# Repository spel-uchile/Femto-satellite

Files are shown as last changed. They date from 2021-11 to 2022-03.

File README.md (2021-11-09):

# README #

Femto-satellite v3.211109

### Description ###

This is a low-cost satellite of less than 100 grams. The goal is to deploy two femto-satellites from a 3U CubeSat to validate a localization system based on TDOA and AOA.

### Current features ###

 * GPS localization
 * S band communication
 * 32-bit ARM Cortex M0+ microcontroller
 * Magnetometer PNI RM3100
 * Data logger using a microSD card
 
### To do ###

 * Update the software for the new hardware version
 * Program a low-power mode

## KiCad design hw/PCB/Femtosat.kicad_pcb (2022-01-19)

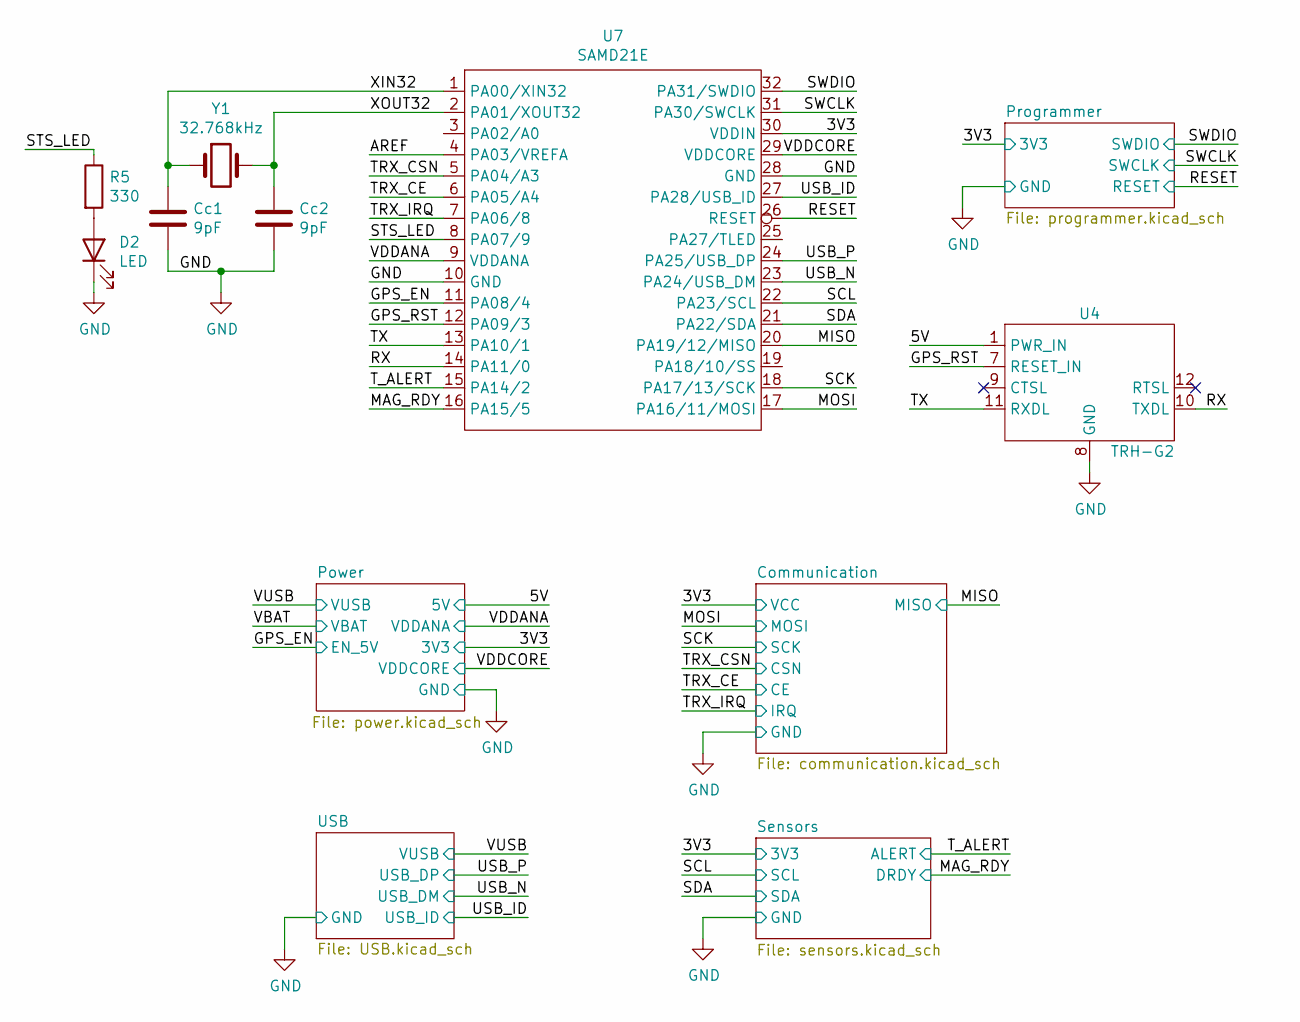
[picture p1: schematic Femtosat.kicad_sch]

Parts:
Cc1, Cc2: 9pF; C_0603_1608Metric_Pad1.05x0.95mm_HandSolder
D2: LED; LED_0805_2012Metric_Pad1.15x1.40mm_HandSolder
R5: 330; R_0603_1608Metric_Pad1.05x0.95mm_HandSolder
U4: TRH-G2; TRH-G2_extended
U7: SAMD21E; TQFP-32_7x7mm_P0.8mm
Y1: 32.768kHz; Crystal_SMD_EuroQuartz_EQ161-2Pin_3.2x1.5mm_HandSoldering

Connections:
+3V3: U7.30 (VDDIN); also elsewhere on the board
/5V: U4.1 (PWR_IN), U4.2 (PWR_IN); also elsewhere on the board
/AREF: U7.4 (PA03/VREFA)
/GPS_EN: U7.11 (PA08/4); also elsewhere on the board
/GPS_RST: U4.7 (RESET_IN), U7.12 (PA09/3)
/MAG_RDY: U7.16 (PA15/5); also elsewhere on the board
/MISO: U7.20 (PA19/12/MISO); also elsewhere on the board
/MOSI: U7.17 (PA16/11/MOSI); also elsewhere on the board
/RESET: U7.26 (RESET); also elsewhere on the board
/RX: U4.10 (TXDL), U7.14 (PA11/0)
/SCK: U7.18 (PA17/13/SCK); also elsewhere on the board
/SCL: U7.22 (PA23/SCL); also elsewhere on the board
/SDA: U7.21 (PA22/SDA); also elsewhere on the board
/STS_LED: R5.1, U7.8 (PA07/9)
/SWCLK: U7.31 (PA30/SWCLK); also elsewhere on the board
/SWDIO: U7.32 (PA31/SWDIO); also elsewhere on the board
/TRX_CE: U7.6 (PA05/A4); also elsewhere on the board
/TRX_CSN: U7.5 (PA04/A3); also elsewhere on the board
/TRX_IRQ: U7.7 (PA06/8); also elsewhere on the board
/TX: U4.11 (RXDL), U7.13 (PA10/1)
/T_ALERT: U7.15 (PA14/2); also elsewhere on the board
/USB_ID: U7.27 (PA28/USB_ID); also elsewhere on the board
/USB_N: U7.23 (PA24/USB_DM); also elsewhere on the board
/USB_P: U7.24 (PA25/USB_DP); also elsewhere on the board
/VDDANA: U7.9 (VDDANA); also elsewhere on the board
/VDDCORE: U7.29 (VDDCORE); also elsewhere on the board
/XIN32: Cc1.1, U7.1 (PA00/XIN32), Y1.1
/XOUT32: Cc2.1, U7.2 (PA01/XOUT32), Y1.2
GND: Cc1.2, Cc2.2, D2.1 (K), U4.3 (PGND), U4.4 (PGND), U4.5 (-), U4.6 (-), U4.8 (GND), U7.10 (GND), U7.28 (GND); also elsewhere on the board
unnamed: D2.2 (A), R5.2

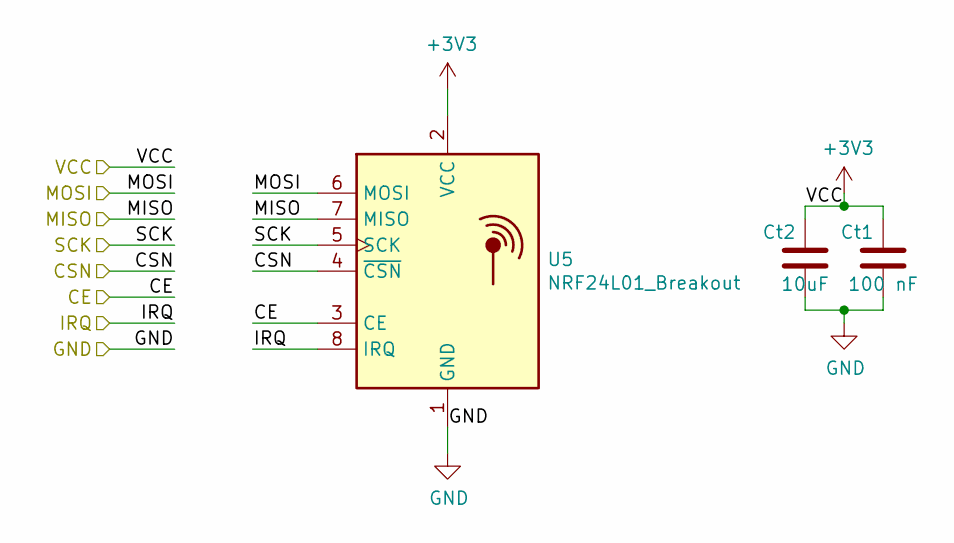
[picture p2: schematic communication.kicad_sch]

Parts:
Ct1: 100 nF; C_0603_1608Metric_Pad1.05x0.95mm_HandSolder
Ct2: 10uF; C_0603_1608Metric_Pad1.05x0.95mm_HandSolder
U5: NRF24L01_Breakout; nRF24L01_long

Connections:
+3V3: Ct1.2, Ct2.2, U5.2 (VCC); also elsewhere on the board
/MISO: U5.7 (MISO); also elsewhere on the board
/MOSI: U5.6 (MOSI); also elsewhere on the board
/SCK: U5.5 (SCK); also elsewhere on the board
/TRX_CE: U5.3 (CE); also elsewhere on the board
/TRX_CSN: U5.4 (~CSN); also elsewhere on the board
/TRX_IRQ: U5.8 (IRQ); also elsewhere on the board
GND: Ct1.1, Ct2.1, U5.1 (GND); also elsewhere on the board

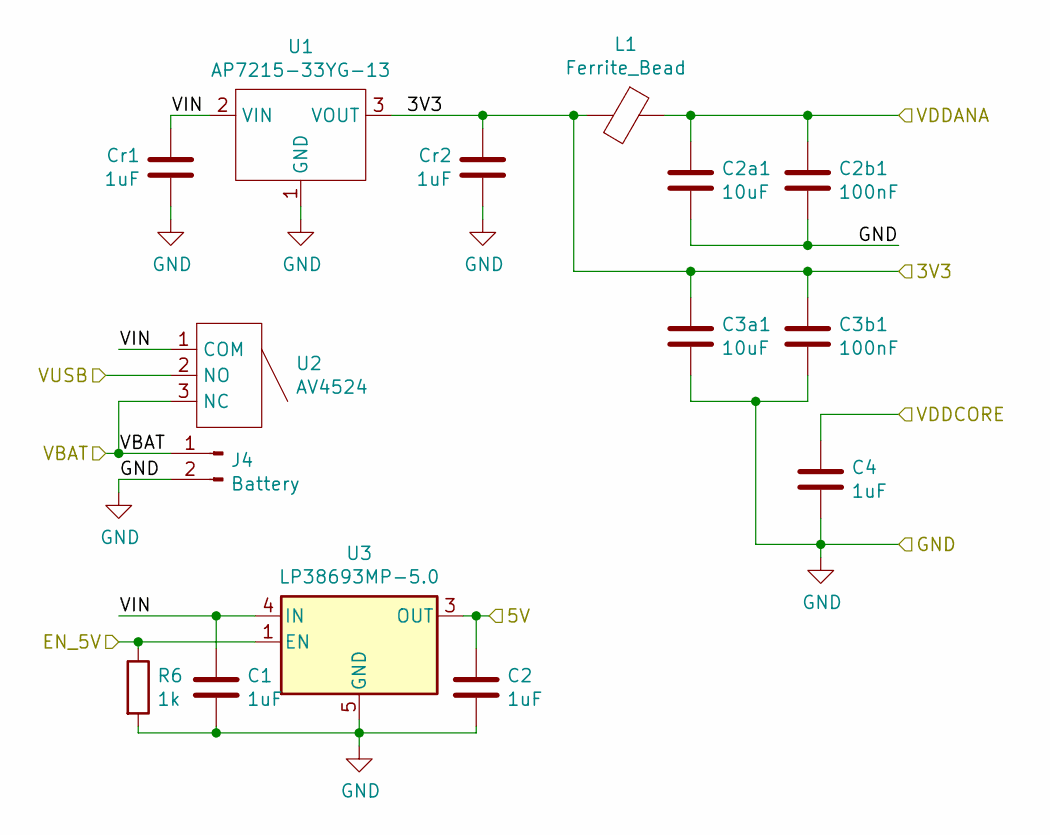
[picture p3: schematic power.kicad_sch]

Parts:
C1, C2, C4: 1uF; C_0603_1608Metric_Pad1.05x0.95mm_HandSolder
C2a1, C3a1: 10uF; C_0603_1608Metric_Pad1.05x0.95mm_HandSolder
C2b1, C3b1: 100nF; C_0603_1608Metric_Pad1.05x0.95mm_HandSolder
Cr1, Cr2: 1uF; C_0603_1608Metric_Pad1.05x0.95mm_HandSolder
J4: Battery; JST_PH_S2B-PH-K_1x02_P2.00mm_Horizontal
L1: Ferrite_Bead; L_0805_2012Metric_Pad1.15x1.40mm_HandSolder
R6: 1k; R_0603_1608Metric_Pad1.05x0.95mm_HandSolder
U1: AP7215-33YG-13; SOT-89-3
U2: AV4524
U3: LP38693MP-5.0; SOT-223-5

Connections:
+3V3: C3a1.1, C3b1.1, Cr2.1, L1.2, U1.3 (VOUT); also elsewhere on the board
/5V: C2.1, U3.3 (OUT); also elsewhere on the board
/GPS_EN: R6.1, U3.1 (EN); also elsewhere on the board
/Power/VIN: C1.1, Cr1.1, U1.2 (VIN), U2.1 (COM), U3.4 (IN)
/VBAT: J4.1, U2.3 (NC)
/VDDANA: C2a1.1, C2b1.1, L1.1; also elsewhere on the board
/VDDCORE: C4.1; also elsewhere on the board
/VUSB: U2.2 (NO); also elsewhere on the board
GND: C1.2, C2.2, C2a1.2, C2b1.2, C3a1.2, C3b1.2, C4.2, Cr1.2, Cr2.2, J4.2, R6.2, U1.1 (GND), U3.5 (GND); also elsewhere on the board

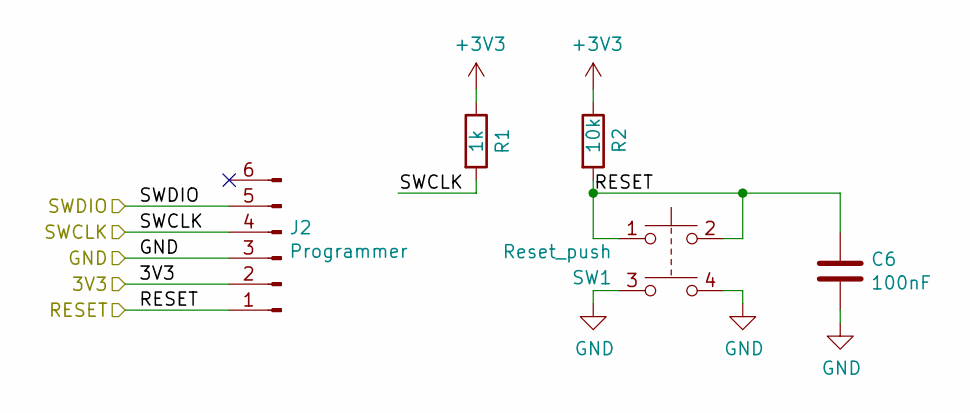
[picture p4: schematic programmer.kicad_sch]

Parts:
C6: 100nF; C_0603_1608Metric_Pad1.05x0.95mm_HandSolder
J2: Programmer; Molex_PicoBlade_53261-0671_1x06-1MP_P1.25mm_Horizontal
R1: 1k; R_0603_1608Metric_Pad1.05x0.95mm_HandSolder
R2: 10k; R_0603_1608Metric_Pad1.05x0.95mm_HandSolder
SW1: Reset_push; SW_TH_Tactile_Omron_B3F-10xx

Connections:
+3V3: J2.2, R1.1, R2.1; also elsewhere on the board
/RESET: C6.1, J2.1, R2.2, SW1.1, SW1.2; also elsewhere on the board
/SWCLK: J2.4, R1.2; also elsewhere on the board
/SWDIO: J2.5; also elsewhere on the board
GND: C6.2, J2.3, SW1.3, SW1.4; also elsewhere on the board

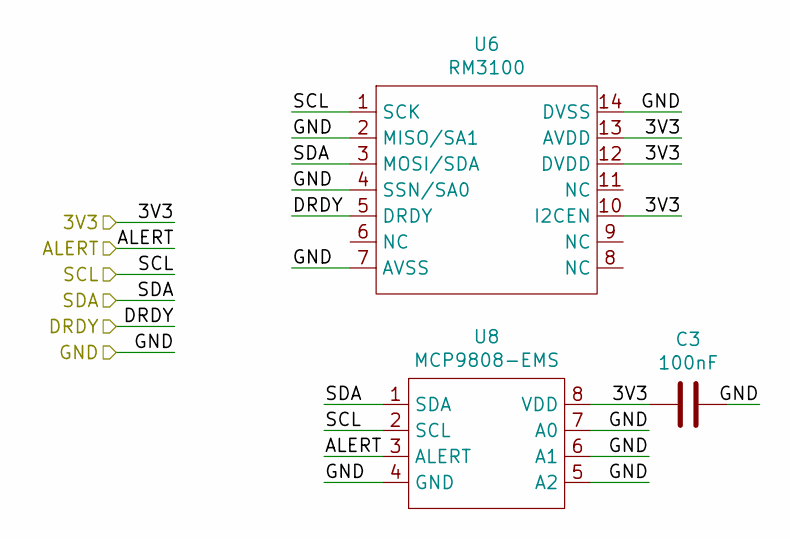
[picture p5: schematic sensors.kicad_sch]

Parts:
C3: 100nF; C_0603_1608Metric_Pad1.05x0.95mm_HandSolder
U6: RM3100
U8: MCP9808-EMS; MSOP-8_3x3mm_P0.65mm

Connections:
+3V3: C3.1, U6.10 (I2CEN), U6.12 (DVDD), U6.13 (AVDD), U8.8 (VDD); also elsewhere on the board
/MAG_RDY: U6.5 (DRDY); also elsewhere on the board
/SCL: U6.1 (SCK), U8.2 (SCL); also elsewhere on the board
/SDA: U6.3 (MOSI/SDA), U8.1 (SDA); also elsewhere on the board
/T_ALERT: U8.3 (ALERT); also elsewhere on the board
GND: C3.2, U6.2 (MISO/SA1), U6.4 (SSN/SA0), U6.7 (AVSS), U6.14 (DVSS), U8.4 (GND), U8.5 (A2), U8.6 (A1), U8.7 (A0); also elsewhere on the board

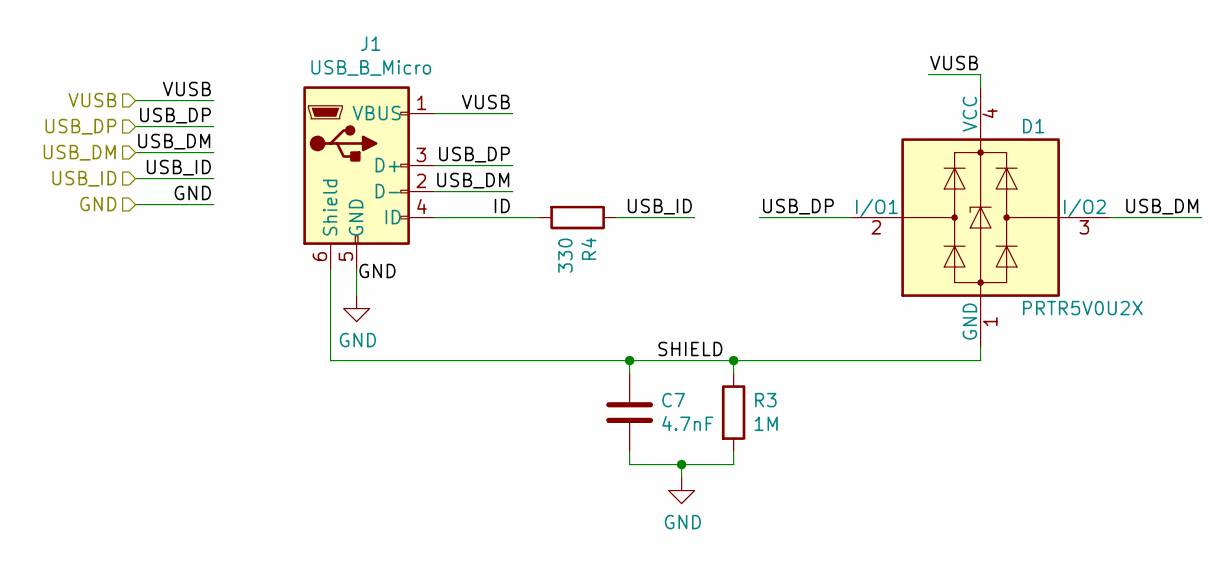
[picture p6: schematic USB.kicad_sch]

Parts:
C7: 4.7nF; C_0603_1608Metric_Pad1.05x0.95mm_HandSolder
D1: PRTR5V0U2X; SOT-143
J1: USB_B_Micro; USB_Micro-B_Molex_47346-0001
R3: 1M; R_0603_1608Metric_Pad1.05x0.95mm_HandSolder
R4: 330; R_0603_1608Metric_Pad1.05x0.95mm_HandSolder

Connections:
/USB/ID: J1.4 (ID), R4.2
/USB/SHIELD: C7.1, D1.1 (GND), J1.6 (Shield), R3.1
/USB_ID: R4.1; also elsewhere on the board
/USB_N: D1.3 (I/O2), J1.2 (D-); also elsewhere on the board
/USB_P: D1.2 (I/O1), J1.3 (D+); also elsewhere on the board
/VUSB: D1.4 (VCC), J1.1 (VBUS); also elsewhere on the board
GND: C7.2, J1.5 (GND), R3.2; also elsewhere on the board

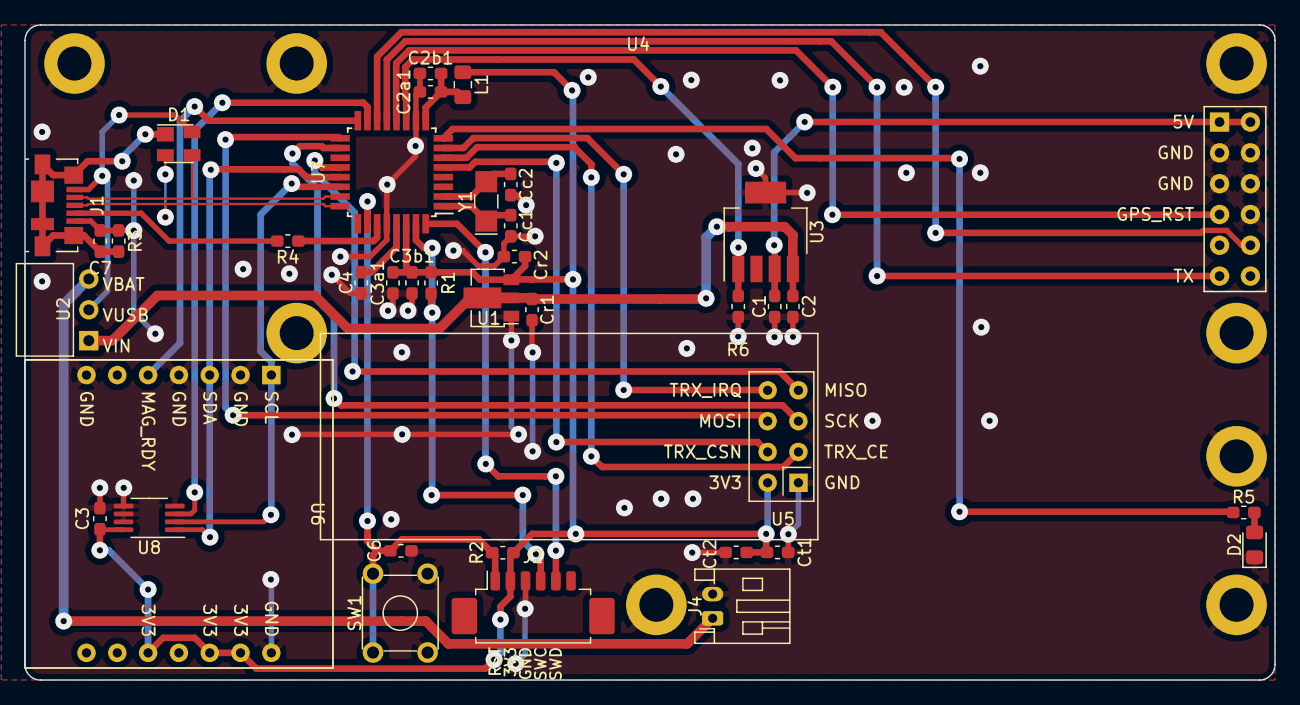
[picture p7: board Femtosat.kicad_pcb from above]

Board: 2 copper layers, 103.1 x 54.0 mm, 38 parts (0 on the bottom side), 34 nets.

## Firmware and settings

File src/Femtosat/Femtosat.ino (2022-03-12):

#include <RTCZero.h>
#include <SPI.h>
#include <Wire.h>
#include "RF24.h"
#include "PNI_RM3100.h"
#include "gps.h"
#include "temp.h"

#define serial SerialUSB
#define STATUS_LED 9
#define RADIO_CE_PIN A4
#define RADIO_CSN_PIN A3
#define MAG_RDY 5
#define TRX_IRQ 8
#define TEMP_ALERT 2
#define START_TRANSMISSION 1

SPIClass mySPI (&sercom1, 12, 13, 11, SPI_PAD_0_SCK_1, SERCOM_RX_PAD_3);
// Instantiate an object for the nRF24L01 transceiver
RF24 radio(RADIO_CE_PIN, RADIO_CSN_PIN, 1000000);
// Instantiate an object for the RM3100 Magnetometer
PNI_RM3100 mag;
// Instantiate an object for the JAVAD GNSS receiver
GPS javad(115200);
// Instantiate an object for the MCP9808 temperature sensor
TEMP temp(0x18);
// Create an rtc object 
RTCZero rtc;

uint8_t address[4][8] = {"Femto 1", "Femto 2", "SUCHAI2", "SUCHAI3"};
uint8_t radioNumber = 1;

// Used to control whether this node is sending or receiving
bool role = false;  // true = TX role, false = RX role

bool mag_debug = false;
bool temp_debug = false;
bool gps_debug = false;
bool trx_debug = false;
uint32_t cmd = 0;
const uint32_t max_samples = 400;
uint32_t transmit_index = 0;

typedef struct{
    uint32_t node = 0;
    uint32_t index = 0;
    uint32_t date = 241121;
    uint32_t time = 16132231;
    int32_t latitude = -3345782;
    int32_t longitude = -7066167;
    int32_t altitude = 505500;
    uint32_t num_sats = 15;
} gnss_data_t;
gnss_data_t gnss_data[max_samples];

typedef struct{
    uint32_t node = 0;
    uint32_t index = 0;
    int32_t fe_mag_x = 5782;
    int32_t fe_mag_y = 6167;
    int32_t fe_mag_z = 9055;
    float temp = 25.0;
} mag_data_t;
mag_data_t mag_data[max_samples];

uint32_t sizeof_gnss_data = sizeof(gnss_data_t);
uint32_t sizeof_mag_data = sizeof(mag_data_t);

void setup() {
    delay(1000);
    Wire.begin();
    pinMode(RADIO_CSN_PIN, OUTPUT);
    digitalWrite(RADIO_CSN_PIN, LOW);
    pinMode(STATUS_LED, OUTPUT);
    digitalWrite(STATUS_LED, LOW);
    pinMode(MAG_RDY, INPUT);
    serial.begin(115200);
    javad.init();
    temp.init();
    if (!mag.begin()) {
        serial.println(F("Could not find a valid RM3100 sensor, check wiring or "
                     "try a different address!"));
    }
    serial.println(F("RM_3100 connected"));
    serial.println(F("Initializing the magnetometer..."));
    /* Default settings from datasheet. */
    int ccx = 3200; /**< Count Cycles for x sensor measurement. It must be between 30 an 400 (default 200) */
    int ccy = 3200; /**< Count Cycles for y sensor measurement. It must be between 30 an 400 (default 200) */
    int ccz = 3200; /**< Count Cycles for z sensor measurement. It must be between 30 an 400 (default 200) */
    mag.setSampling(PNI_RM3100::MODE_CMMXYZ,     /* Operating Mode. MODE_SINGLE MODE_CMMXYZ MODE_CMMX MODE_CMMY MODE_CMMZ*/
                    PNI_RM3100::TMRC_HZ,         /* Max frequency */
                    ccx,    /**< Count Cycles for x sensor measurement. It must be between 30 an 400 (default 200) */
                    ccy,    /**< Count Cycles for y sensor measurement. It must be between 30 an 400 (default 200) */
                    ccz,    /**< Count Cycles for z sensor measurement. It must be between 30 an 400 (default 200) */
                    1);
    serial.println(F("Done."));
    while (!radio.begin(&mySPI, RADIO_CE_PIN, RADIO_CSN_PIN)) {
        serial.println(F("Radio hardware is not responding!!"));
        delay(1000);
    }
    serial.println(F("Initializing radio hardware..."));
    radio.setPALevel(RF24_PA_MAX);//LOW);  // RF24_PA_MAX is default.
    radio.setPayloadSize(sizeof_gnss_data);
    radio.openWritingPipe(address[radioNumber]);
    radio.openReadingPipe(1, address[3]);
    radio.setDataRate(RF24_250KBPS);
    radio.setChannel(55); // 2400 + 55 = 2455 MHz
    radio.startListening(); // put radio in RX mode
    serial.println(F("Done."));
    serial.println(F("Initializing RTC..."));
    rtc.begin();
    rtc.setTime((byte) 0, (byte) 0, (byte) 0);
    rtc.setDate((byte) 0, (byte) 0, (byte) 0);
    serial.println(F("Done."));
    digitalWrite(STATUS_LED, HIGH);
    delay(5000);
    digitalWrite(STATUS_LED, LOW);
    //role = true;
    //cmd = 8;
    serial.println(F("Starting initial measurement."));
    updateData();
    serial.println(F("Done."));
} // setup

void loop() {
    if (role) {
        if (cmd == 0) {
            sendGPSData(transmit_index);
        }
        else if (cmd == 1){
            sendMagData(transmit_index);
        }
        else if (cmd == 2) {
            sendCarrierWave();
        }
        else {
            setAlarm(cmd);
            delay(200);
            updateData();
            //role = true;
        }
        transmit_index++;
        //serial.println(transmit_index);
        delay(10);
        if (transmit_index >= max_samples*2) {
            transmit_index = 0;
            setAlarm(4800);
            delay(200);
            updateData();
        }
    }
    else {
        receiveCMD();
    } // role
} // loop

/**
 * Enables the low power mode of operation
 * of the femto-satellite.
 * Currently it only puts the radio to sleep,
 * but it is expected to also put the
 * microcontroller into this state.
 */
void lowPowerMode() {
    serial.println(F("Low power mode selected"));
    javad.powerDown();
    radio.powerDown();
    digitalWrite(STATUS_LED, LOW);
}

/**
 * Enables the normal mode of operation.
 */
void normalMode() {
    serial.println(F("Normal mode selected"));
    javad.powerDown();
    radio.powerUp();
    delay(5);
    radio.startListening();
}

void setAlarm(uint32_t dt) {
    uint32_t hours, minutes;
    lowPowerMode();
    role = false;
    rtc.setTime((byte) 0, (byte) 0, (byte) 0);
    hours = dt/3600;
    serial.println(F("========================================"));
    if (hours > 0) {
        dt = dt - hours*3600;
        serial.print(F("Hours: "));
        serial.println(hours);
    }
    minutes = dt/60;
    if (minutes > 0) {
        dt = dt - minutes*60;
        serial.print(F("Minutes: "));
        serial.println(minutes);
    }
    serial.print(F("Seconds: "));
    serial.println(dt);
    rtc.setAlarmTime((byte) hours, (byte) minutes, (byte) dt);
    rtc.enableAlarm(rtc.MATCH_HHMMSS);
    //rtc.attachInterrupt(updateData);
    rtc.standbyMode();
}

void sendCarrierWave() {
    serial.println("Sending a constant carrier wave");
    radio.startConstCarrier(RF24_PA_MAX, 55);
    delay(5000);
    radio.stopConstCarrier();
    radio.startListening();
    serial.println("Stopped constant carrier wave");
    role = false;
}

void sendGPSData(uint32_t index) {
    radio.setPayloadSize(sizeof_gnss_data);
    unsigned long start_timer = micros();                     // start the timer
    bool report = radio.write(&gnss_data[index], sizeof_gnss_data); // transmit & save the report
    unsigned long end_timer = micros();                       // end the timer
    if (report) {
        if (trx_debug) {
            serial.print(F("Transmission successful! Time to transmit = ")); // payload was delivered
            serial.print(end_timer - start_timer);                           // print the timer result
            serial.println(F(" us. Sent: Node: "));
            serial.print(gnss_data[index].node);
            serial.print(F(" Index: "));
            serial.print(gnss_data[index].index);
            serial.print(F(" Date: "));
            serial.print(gnss_data[index].date);
            serial.print(F(" Time: "));
            serial.print(gnss_data[index].time);
            serial.print(F(" Latitude: "));
            serial.print(gnss_data[index].latitude);
            serial.print(F(" Longitude: "));
            serial.print(gnss_data[index].longitude);
            serial.print(F(" Altitude: "));
            serial.print(gnss_data[index].altitude);
            serial.print(F(" Number of sats.: "));
            serial.print(gnss_data[index].num_sats);
            serial.print(F("\n"));
        }
        radio.startListening();
    }
    else {
        serial.println(F("Transmission failed or timed out")); // payload was not delivered
    }
    role = false;
    radio.startListening();
}

void sendMagData(uint32_t index) {
    radio.setPayloadSize(sizeof_mag_data);
    unsigned long start_timer = micros();                     // start the timer
    bool report = radio.write(&mag_data[index], sizeof_mag_data);   // transmit & save the report
    unsigned long end_timer = micros();                       // end the timer
    if (report) {
        if (trx_debug) {
            serial.print(F("Transmission successful! Time to transmit = ")); // payload was delivered
            serial.print(end_timer - start_timer);                           // print the timer result
            serial.println(F(" us. Sent: Node: "));
            serial.print(mag_data[index].node);
            serial.print(F(" Index: "));
            serial.print(mag_data[index].index);
            serial.print(F(" Magnetometer X: "));
            serial.print(mag_data[index].fe_mag_x);
            serial.print(F(" Magnetometer Y: "));
            serial.print(mag_data[index].fe_mag_y);
            serial.print(F(" Magnetometer Z: "));
            serial.print(mag_data[index].fe_mag_z);
            serial.print(F("\n"));
        }
        radio.startListening();
    }
    else {
        serial.println(F("Transmission failed or timed out")); // payload was not delivered
    }
    role = false;
    radio.startListening();
}

void receiveCMD() {
    // This device is a RX node
    radio.setPayloadSize(sizeof(cmd));
    uint8_t pipe;
    if (radio.available(&pipe)) {             // is there a payload? get the pipe number that recieved it
        //radio.setPayloadSize(sizeof(uint32_t));
        uint8_t bytes = radio.getPayloadSize(); // get the size of the payload
        radio.read(&cmd, bytes);            // fetch payload from FIFO
        serial.println(cmd);
        if (trx_debug) {
            serial.print(F("Received "));
            serial.print(bytes);                    // print the size of the payload
            serial.print(F(" bytes on pipe "));
            serial.print(pipe);                     // print the pipe number
            serial.print(F(": "));
            serial.print(cmd);                // print the payload's value
            serial.print(F("   Binary: "));
            serial.println(cmd, BIN);
        }
        role = true;
        radio.stopListening();
    }
}

void updateGPSData(uint32_t index) {
    digitalWrite(STATUS_LED, HIGH);
    if (Serial1.available()) {
        javad.updateData();
        javad.checkValidity();
        gnss_data[index].index = index;
        gnss_data[index].date = javad.gpsData.date;
        gnss_data[index].time = javad.gpsData.time;
        gnss_data[index].latitude = javad.gpsData.latitude;
        gnss_data[index].longitude = javad.gpsData.longitude;
        gnss_data[index].altitude = javad.gpsData.altitude;
        gnss_data[index].num_sats = javad.gpsData.num_sats;
        if (gps_debug) {
            serial.print(F("Node: "));
            serial.print(gnss_data[index].node);
            serial.print(F("  Index: "));
            serial.print(gnss_data[index].index);
            serial.print(F("  Date: "));
            serial.print(gnss_data[index].date);
            serial.print(F("  Time: "));
            serial.print(gnss_data[index].time);
            serial.print(F(" Lat: "));
            serial.print(gnss_data[index].latitude);
            serial.print(F("° Lng: "));
            serial.print(gnss_data[index].longitude);
            serial.print(F("° Alt:"));
            serial.print(gnss_data[index].altitude);
            serial.print(F(" [m] Sats: "));
            serial.println(gnss_data[index].num_sats);
        }
    }
    digitalWrite(STATUS_LED, LOW);
}

void updateMagData(uint32_t index) {
    digitalWrite(STATUS_LED, HIGH);
    bool checking;
    RM3100_measurements data;
    checking = mag.check_masurement();
    if (checking) {
        data = mag.readMagneticField();
        mag_data[index].index = index;
        mag_data[index].fe_mag_x = data.mag_x;
        mag_data[index].fe_mag_y = data.mag_y;
        mag_data[index].fe_mag_z = data.mag_z;
        if (mag_debug) {
            serial.print(F("Node: "));
            serial.print(mag_data[index].node);
            serial.print(F("  Index: "));
            serial.print(mag_data[index].index);
            serial.print(F("  Mag X: "));
            serial.print(mag_data[index].fe_mag_x);
            serial.print(F("  Mag Y: "));
            serial.print(mag_data[index].fe_mag_y);
            serial.print(F("  Mag Z: "));
            serial.print(mag_data[index].fe_mag_z);
        }
    }
    digitalWrite(STATUS_LED, LOW);
}

void updateTempData(uint32_t index) {
    if (temp.checkValidity()) {
        digitalWrite(STATUS_LED, HIGH);
        mag_data[index].temp = temp.updateData();
        if (temp_debug) {
            serial.print(F("  Temp: "));
            serial.print(mag_data[index].temp);
            serial.println(F(" [°C]"));
        }
    }
    else
        serial.println(F("Data invalid!"));
    digitalWrite(STATUS_LED, LOW);
}

void updateData() {
    digitalWrite(STATUS_LED, LOW);
    radio.stopListening();
    radio.powerDown();
    javad.powerUp();
    delay(100);
    int ttff = 20000;

    serial.println(F("Configuring GNSS receiver with %%set,/par/lock/vmax,10000..."));
    Serial1.print(F("%%set,/par/lock/vmax,10000"));
    //while (Serial1.available())
    //    serial.print(Serial1.read());
    serial.println(F("Done."));
    serial.println(F("Configuring GNSS receiver with %%set,/par/pwr/extanten,on..."));
    Serial1.print(F("%%set,/par/pwr/extanten,on"));
    //while (Serial1.available())
    //    serial.print(Serial1.read());
    serial.println(F("Done."));
    serial.println(F("Configuring GNSS receiver with em,,nmea/{GGA,ZDA}:0.3..."));
    Serial1.print(F("em,,nmea/{GGA,ZDA}:0.3"));
    //while (Serial1.available())
    //    serial.print(Serial1.read());
    serial.println(F("Done."));
    delay(ttff);

/*
    for (int i =0; i < 100; i++) {
        serial.println(F("Reading GPS data..."));
        updateGPSData(0);
        delay(300);
    }
*/
    uint32_t i = 0;
    while (i < max_samples) {
        if (digitalRead(MAG_RDY)) {
            updateGPSData(i);
            updateMagData(i);
            updateTempData(i);
            i++;
        }
        delay(20);
    }
    javad.powerDown();
    radio.powerUp();
    radio.startListening();
    role = false;
}

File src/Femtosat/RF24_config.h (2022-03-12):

/*
 Copyright (C)
    2011            J. Coliz <maniacbug@ymail.com>
    2015-2019       TMRh20
    2015            spaniakos <spaniakos@gmail.com>
    2015            nerdralph
    2015            zador-blood-stained
    2016            akatran
    2017-2019       Avamander <avamander@gmail.com>
    2019            IkpeohaGodson
    2021            2bndy5

 This program is free software; you can redistribute it and/or
 modify it under the terms of the GNU General Public License
 version 2 as published by the Free Software Foundation.
*/

#ifndef __RF24_CONFIG_H__
#define __RF24_CONFIG_H__

/*** USER DEFINES:    ***/
#define FAILURE_HANDLING
//#define SERIAL_DEBUG
//#define MINIMAL
//#define SPI_UART    // Requires library from https://github.com/TMRh20/Sketches/tree/master/SPI_UART
//#define SOFTSPI     // Requires library from https://github.com/greiman/DigitalIO

/**
 * User access to internally used delay time (in microseconds) during RF24::powerUp()
 * @warning This default value compensates for all supported hardware. Only adjust this if you
 * know your radio's hardware is, in fact, genuine and reliable.
 */
#if !defined(RF24_POWERUP_DELAY)
#define RF24_POWERUP_DELAY	5000
#endif

/**********************/
#define rf24_max(a, b) (a>b?a:b)
#define rf24_min(a, b) (a<b?a:b)

/** @brief The default SPI speed (in Hz) */
#ifndef RF24_SPI_SPEED
#define RF24_SPI_SPEED 10000000
#endif

//ATXMega
#if defined (__AVR_ATxmega64D3__) || defined (__AVR_ATxmega128D3__) || defined (__AVR_ATxmega192D3__) || defined (__AVR_ATxmega256D3__) || defined (__AVR_ATxmega384D3__)
// In order to be available both in Windows and Linux this should take presence here.
    #define XMEGA
    #define XMEGA_D3
    #include "utility/ATXMegaD3/RF24_arch_config.h"

// RaspberryPi rp2xxx-based devices (e.g. RPi Pico board)
#elif defined (PICO_BUILD) && !defined (ARDUINO)
    #include "utility/rp2/RF24_arch_config.h"

#elif (!defined (ARDUINO)) // Any non-arduino device is handled via configure/Makefile
    // The configure script detects device and copies the correct includes.h file to /utility/includes.h
    // This behavior can be overridden by calling configure with respective parameters
    // The includes.h file defines either RF24_RPi, MRAA, LITTLEWIRE or RF24_SPIDEV and includes the correct RF24_arch_config.h file
    #include "utility/includes.h"

//ATTiny
#elif defined (__AVR_ATtiny25__) || defined (__AVR_ATtiny45__) || defined (__AVR_ATtiny85__) || defined (__AVR_ATtiny24__) || defined (__AVR_ATtiny44__) || defined (__AVR_ATtiny84__) || defined (__AVR_ATtiny2313__) || defined (__AVR_ATtiny4313__) || defined (__AVR_ATtiny861__) || defined (__AVR_ATtinyX5__) || defined (__AVR_ATtinyX4__) || defined (__AVR_ATtinyX313__) || defined (__AVR_ATtinyX61__)
    #define RF24_TINY
    #include "utility/ATTiny/RF24_arch_config.h"

#elif defined (LITTLEWIRE) //LittleWire
    #include "utility/LittleWire/RF24_arch_config.h"

#elif defined (TEENSYDUINO) //Teensy
    #include "utility/Teensy/RF24_arch_config.h"

#else //Everything else
    #include <Arduino.h>


    #if defined (ARDUINO) && !defined (__arm__) && !defined (__ARDUINO_X86__)
        #if defined SPI_UART
            #include <SPI_UART.h>
            #define _SPI uspi
        #elif defined (SOFTSPI)
            // change these pins to your liking
            //
            #ifndef SOFT_SPI_MISO_PIN
                #define SOFT_SPI_MISO_PIN 9
            #endif // SOFT_SPI_MISO_PIN

            #ifndef SOFT_SPI_MOSI_PIN
                #define SOFT_SPI_MOSI_PIN 8
            #endif // SOFT_SPI_MOSI_PIN

            #ifndef SOFT_SPI_SCK_PIN
                #define SOFT_SPI_SCK_PIN 7
            #endif // SOFT_SPI_SCK_PIN

            const uint8_t SPI_MODE = 0;
            #define _SPI spi

        #elif defined (ARDUINO_SAM_DUE)
            #include <SPI.h>
            #define _SPI SPI

        #else // !defined (SPI_UART) && !defined (SOFTSPI)
            #include <SPI.h>
            #define _SPI SPIClass
            #define RF24_SPI_PTR
        #endif // !defined (SPI_UART) && !defined (SOFTSPI)

    #else // !defined(ARDUINO) || defined (__arm__) || defined (__ARDUINO_X86__)
        // Define _BV for non-Arduino platforms and for Arduino DUE
        #include <stdint.h>
        #include <stdio.h>
        #include <string.h>

        #if defined (__arm__) || defined (__ARDUINO_X86__)
            #if defined (__arm__) && defined (SPI_UART)
                #include <SPI_UART.h>
                #define _SPI uspi

            #else // !defined (__arm__) || !defined (SPI_UART)
                #include <SPI.h>
                #define _SPI SPIClass
                #define RF24_SPI_PTR
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

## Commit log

2018-10-25 Added schematic of the femto-satellite's PCB.
    [Femtosat.kicad_pcb, Femtosat.sch, USB.sch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]
2018-10-25 Added library for certain components. Symbols and footprints were associated.
    [Femtosat.kicad_pcb, Femtosat.sch, USB.sch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]
2018-10-30 Added PCB template with the shape of the TRH-G2 GPS.
2018-10-30 Added capacitors for the communication system.
    [Femtosat.kicad_pcb, communication.sch]
2018-10-31 Checking for the component's placement on the board.
    [Femtosat.kicad_pcb]
2018-11-15 Added the Arduino library that contains the pinout of the SAMD21 microcontroller.
2018-11-15 Added library for the power regulator.
2018-11-15 Changed the XA1110 GPS footprint's first pin to a rectangular shape.
    [Femtosat.kicad_pcb]
2018-11-22 Inscreased the size of the mechanical holes and their pads. Fixed an error in the position of the pins.
    [Femtosat.kicad_pcb]
2018-11-22 Fixed pads' position error and updated the PCB.
    [Femtosat.kicad_pcb]
2018-11-22 Deleted the GPS device (moved to another PCB). Added the deploy-sensor (an interrupter). Moved the programmer to its own hierarchical sheet.
    [Femtosat.kicad_pcb, Femtosat.sch, USB.sch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]
2018-11-22 Associated the new symbols to their respective footprints.
    [Femtosat.kicad_pcb, Femtosat.sch, USB.sch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]
2018-11-23 Minor changes.
    [Femtosat.kicad_pcb, communication.sch, power.sch]
2018-11-27 Routed all tracks.
    [Femtosat.kicad_pcb, Femtosat.sch, power.sch]
2018-11-28 Fixed error in which the GPS was in the top layer instead of the bottom layer. Version 1 released. Changed PCB's folder name to PCB.
    [Femtosat.kicad_pcb, Femtosat.sch, USB.sch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]
2018-11-28 Exported CAD model of the femto-satellite's PCB.
2018-11-28 Minor changes
    [Femtosat.kicad_pcb]
2018-11-28 Generated gerber files.
    [Femtosat.drl, Femtosat.gbl, Femtosat.gbo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]
2018-11-28 Added more labels in the Silk layer.
    [Femtosat.kicad_pcb]
2018-11-28 Created new gerber files.
    [Femtosat.drl, Femtosat.gbl, Femtosat.gbo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]
2018-11-28 Exported new CAD design.
2019-04-29 Specified the capacitance of the transceiver's capacitors. Updated the path of the library for the RFM69HCW.
    [Femtosat.sch, USB.sch, communication.sch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]
2019-07-03 Added a footprint library for a micro SD card. Updated the schematic. Replaced the SAMD21G with the SAMD21E (32 pin variant). Added a data logger and a reset button.
    [Femtosat.sch, USB.sch, communication.sch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]
2019-07-04 Added pullup resistor to the chip-select pin of the uSD card slot.
    [Femtosat.sch, data_logger.sch]
2019-07-04 Started the new design of the PCB's layout.
    [Femtosat.kicad_pcb, USB.sch, communication.sch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]
2019-07-05 Replaced a 100nF capacitor with a 10uF capacitor. Worked on PCB preliminary layout.
    [Femtosat.kicad_pcb, power.sch]
2019-07-05 Ended preliminary design phase.
    [Femtosat.kicad_pcb, Femtosat.sch]
2019-07-09 Final revision check. Generated the Gerber files.
    [FE2.drl, FE2.gbl, FE2.gbo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]
2019-07-09 Generated a new CAD file for the 2.0 version.
2019-07-12 Reploted the Gerber files.
    [FE2.drl, FE2.gbl, FE2.gbo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]
2019-07-12 Generated a new CAD file for the femto-satellite v2.0.
2019-07-18 Changed the pin order of the pin header to connect the femto-satellite to the GPS TRH-G2. Now this connector has a battery voltage input for a future EPS board.
    [FE2.drl, FE2.gbl, FE2.gbo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]
2019-07-19 Increased the size of the pad and the drill of the interrupter.
    [FE_v2.drl, FE_v2.gbl, FE_v2.gbo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]
2021-10-25 New design of the femto-satellite. Deleted UHF transceiver and added another one in S band. Changed the magnetometer. Added more space.
    [FE_v2.drl, FE_v2.gbl, FE_v2.gbo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]
2021-10-25 New CAD file.
2021-10-26 Added a logo to the PCB.
    [Femtosat.kicad_pcb]
2021-10-26 Generated new Gerber files.
    [FE_v3.drl, FE_v3.gbl, FE_v3.gbo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]
2021-10-26 Generated a new CAD file.
2022-01-19 Added temperature sensor.
2022-01-19 Modified the design of the femto-satellite. Now it is smaller an it has a temperature sensor to calibrate the magnetometer.
    [FE_v3.drl, FE_v3.gbl, FE_v3.gbo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]
2022-02-26 Added a temperature sensor, a GPS receiver and improved the software.
